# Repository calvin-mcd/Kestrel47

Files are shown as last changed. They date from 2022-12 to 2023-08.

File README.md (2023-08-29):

# Kestrel47

collaboration with Falconloft\#4615

40s keyboard inspired by the TG4x. sandwich style case with midlayers case. Supports Bluetooth enabled micro controllers with use of this [power button](https://tech.alpsalpine.com/e/products/detail/SSSS811101/) as well as smd and throughhole style diodes.

Firmware for standard atmega & rp2040 pro micro style controllers is included. Bluetooth is supported for bluemicro style controllers.

concept, case design and firmware by Falconloft\#4615, pcb design by Calvin\#0563

## Layout

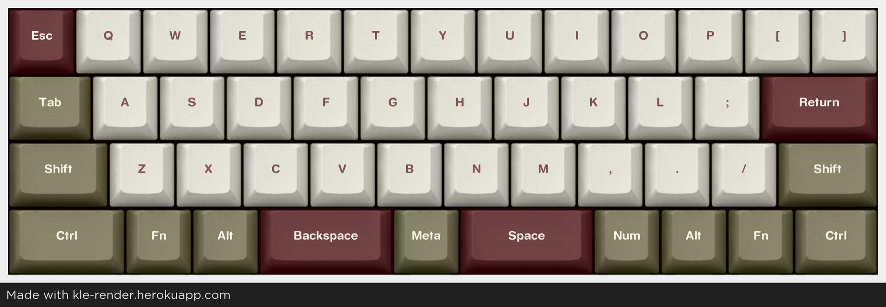
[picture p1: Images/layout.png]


[Link](http://www.keyboard-layout-editor.com/#/gists/43b69fae42faf7c21a81fad3a4cf8861)

## Pictures

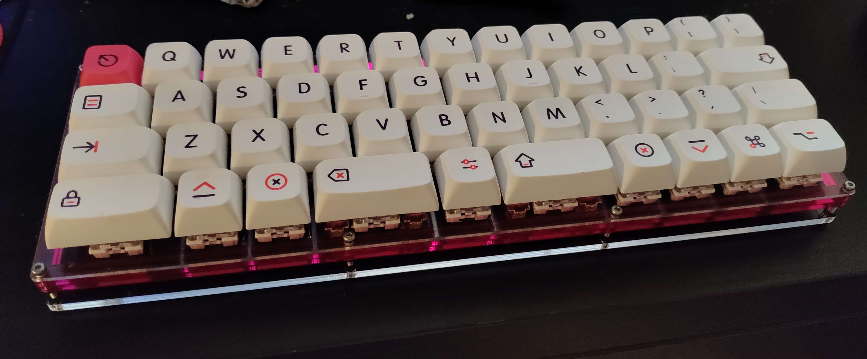
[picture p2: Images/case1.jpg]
  
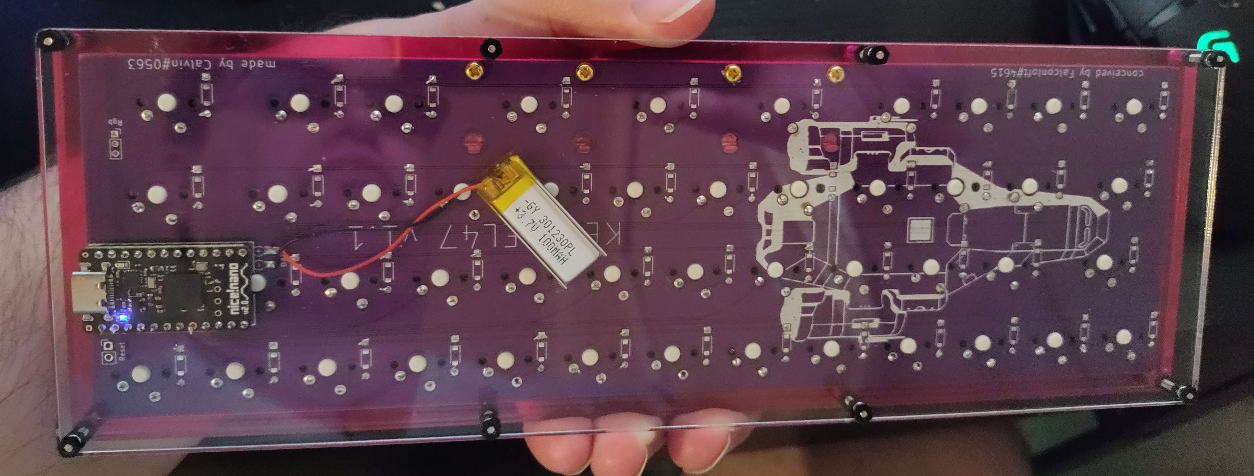
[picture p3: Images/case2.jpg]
  
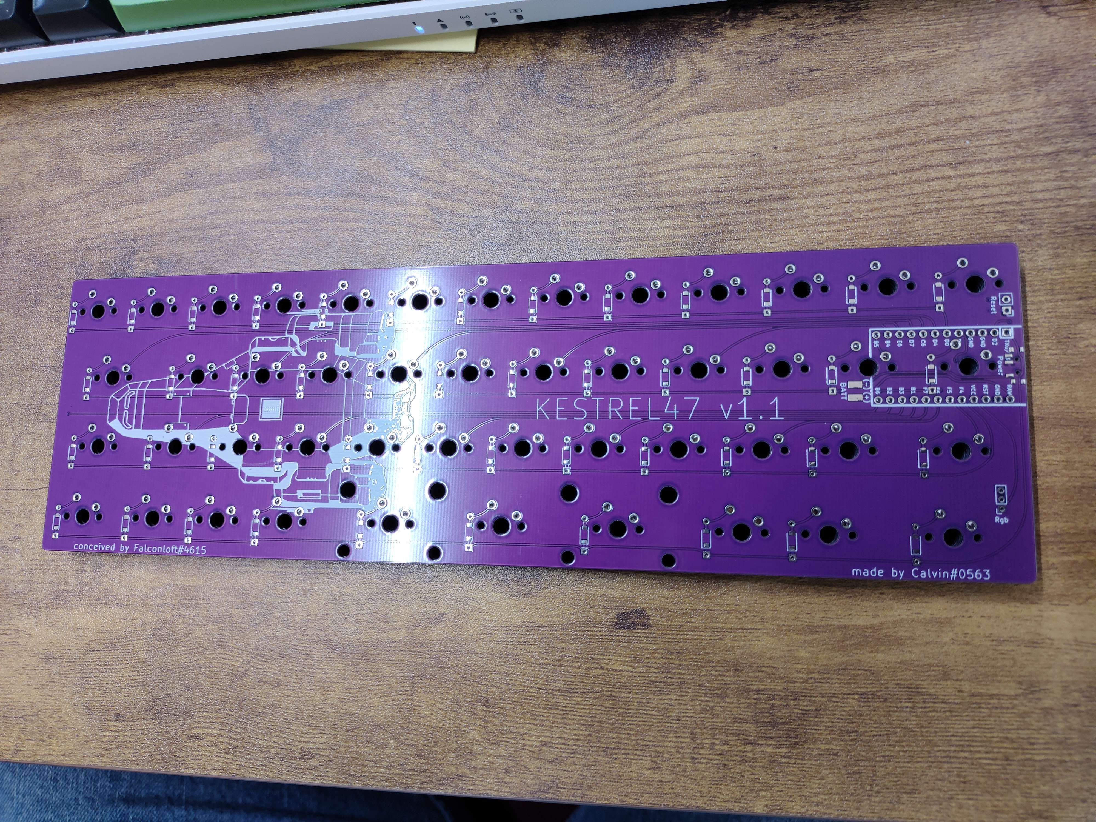
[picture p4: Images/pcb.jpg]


## Firmware

Firmware for both Atmega and rp2040 controllers is functional and included.

The Bluetooth firmware is zmk based, functional and included.

## Disclaimer

This PCB has been fully tested and confirmed to work. The members of the PCB development team are however not liable if you end up with a non-functional pcb. Order at your own risk. Support will not be provided but pull requests will be reviewed and possibly accepted.

## License

Shield: 

This work is licensed under a  
[Creative Commons Attribution-NonCommercial-ShareAlike 4.0 International License](http://creativecommons.org/licenses/by-nc-sa/4.0/).



## Credits

Any questions, contact Falconloft\#4615 & Calvin\#0563 on Discord.

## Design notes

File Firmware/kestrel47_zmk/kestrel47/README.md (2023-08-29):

# Kestrel47

Standard setup for the [Kestrel47](https://github.com/calvin-mcd/Kestrel47/) 40% keyboard.

## Board Revision and Layout Notes

This Kestrel47 implementation is for...

- rev 1.1 of the board

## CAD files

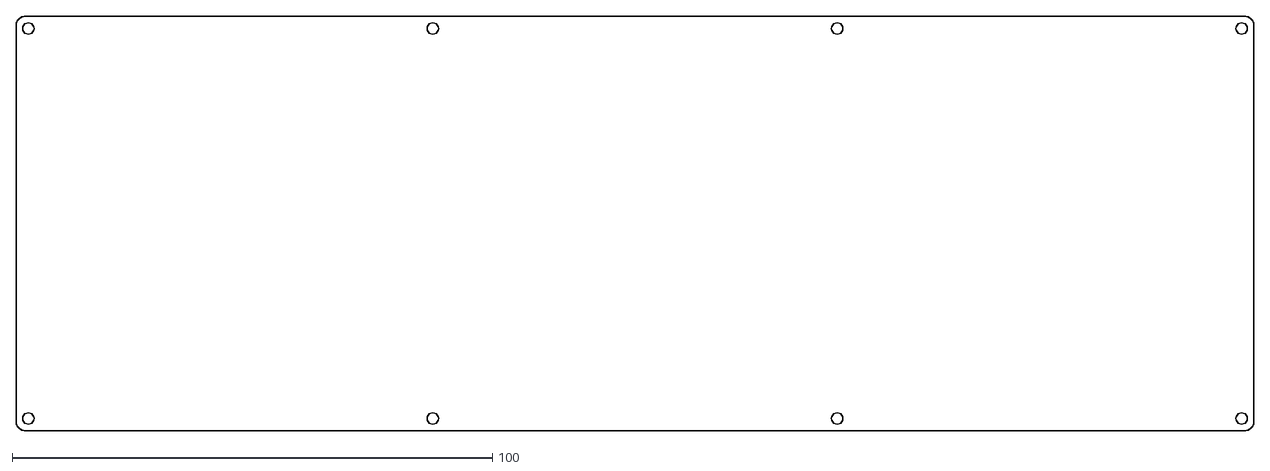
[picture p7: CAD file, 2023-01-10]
Case/kestrel47_bottom.dxf
257.8 x 86.3

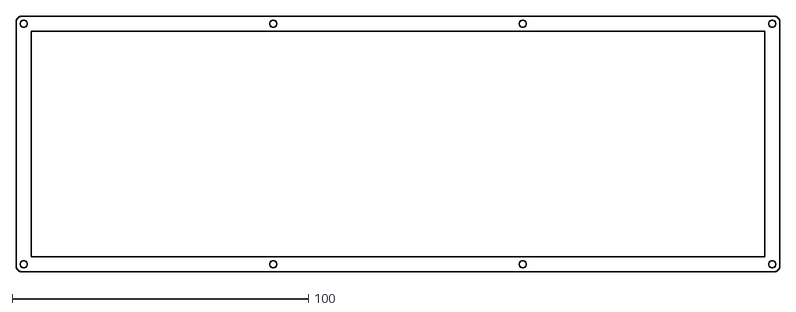
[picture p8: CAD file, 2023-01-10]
Case/kestrel47_closed.dxf
257.8 x 86.3

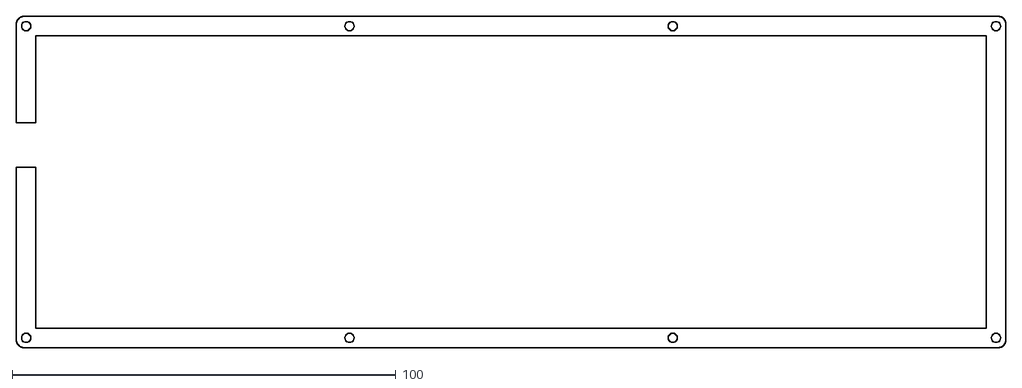
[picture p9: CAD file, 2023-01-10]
Case/kestrel47_open.dxf
257.8 x 86.3

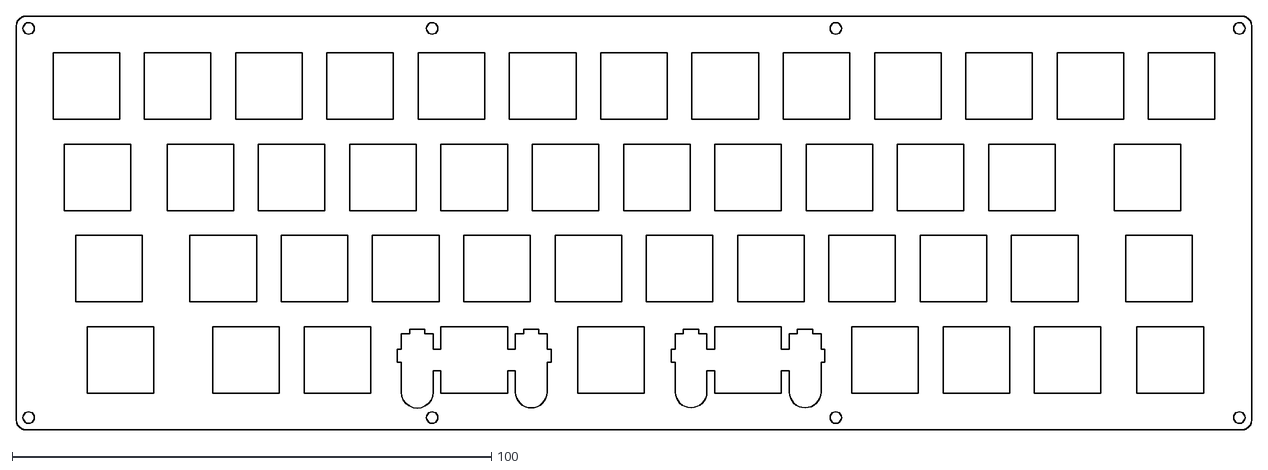
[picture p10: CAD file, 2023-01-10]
Case/kestrel47_switch.dxf
257.8 x 86.3

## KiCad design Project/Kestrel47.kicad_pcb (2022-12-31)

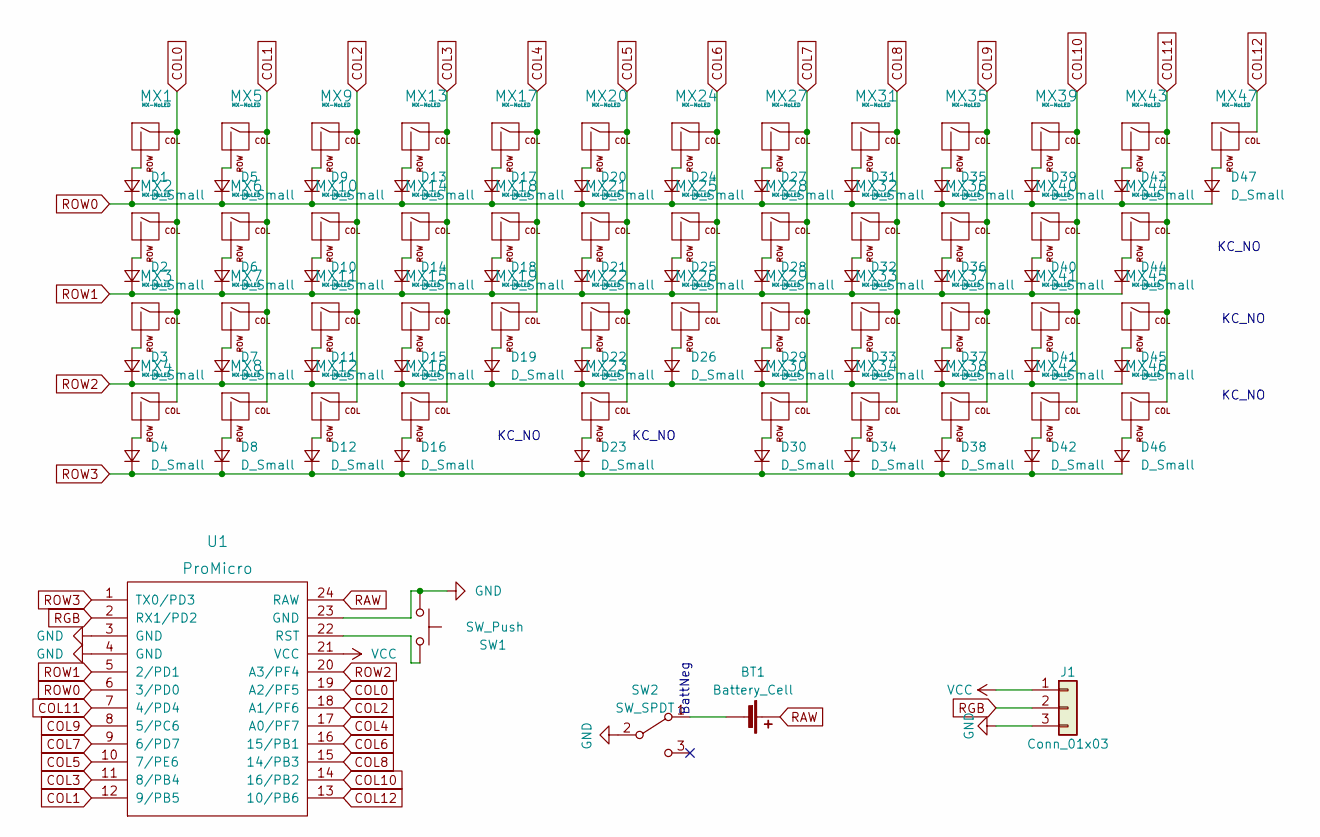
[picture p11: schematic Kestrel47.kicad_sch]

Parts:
BT1: Battery_Cell; cell_pads
D1, D2, D3, D4, D5, D6, D7, D8, D9, D10, D11, D12, D13, D14, D15, D16, D17, D18, D19, D20, D21, D22, D23, D24, D25, D26, D27, D28, D29, D30, D31, D32, D33, D34, D35, D36, D37, D38, D39, D40, D41, D42, D43, D44, D45, D46, D47: D_Small; ComboDiode
J1: Conn_01x03; PinSocket_1x03_P2.00mm_Vertical
MX1, MX5, MX6, MX7, MX8, MX9, MX10, MX11, MX12, MX13, MX14, MX15, MX17, MX18, MX19, MX20, MX21, MX22, MX23, MX24, MX25, MX26, MX27, MX28, MX29, MX31, MX32, MX33, MX34, MX35, MX36, MX37, MX38, MX39, MX40, MX41, MX42, MX43, MX47: MX-NoLED; MXOnly-1U-NoLED
MX2, MX46: MX-NoLED; MXOnly-1.25U-NoLED
MX3, MX45: MX-NoLED; MXOnly-1.5U-NoLED
MX4, MX44: MX-NoLED; MXOnly-1.75U-NoLED
MX16, MX30: MX-NoLED; MXOnly-2U-ReversedStabilizers-NoLED
SW1: SW_Push; PinHeader_1x02_P2.54mm_Vertical
SW2: SW_SPDT; switch_SSSS811101
U1: ProMicro; ArduinoProMicro

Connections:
ROW3: D4.1 (K), D8.1 (K), D12.1 (K), D16.1 (K), D23.1 (K), D30.1 (K), D34.1 (K), D38.1 (K), D42.1 (K), D46.1 (K), U1.1 (TX0/PD3)
COL0: MX1.1 (COL), MX2.1 (COL), MX3.1 (COL), MX4.1 (COL), U1.19 (A2/PF5)
COL1: MX5.1 (COL), MX6.1 (COL), MX7.1 (COL), MX8.1 (COL), U1.12 (9/PB5)
COL2: MX9.1 (COL), MX10.1 (COL), MX11.1 (COL), MX12.1 (COL), U1.18 (A1/PF6)
COL3: MX13.1 (COL), MX14.1 (COL), MX15.1 (COL), MX16.1 (COL), U1.11 (8/PB4)
COL4: MX17.1 (COL), MX18.1 (COL), MX19.1 (COL), U1.17 (A0/PF7)
COL5: MX20.1 (COL), MX21.1 (COL), MX22.1 (COL), MX23.1 (COL), U1.10 (7/PE6)
COL6: MX24.1 (COL), MX25.1 (COL), MX26.1 (COL), U1.16 (15/PB1)
COL7: MX27.1 (COL), MX28.1 (COL), MX29.1 (COL), MX30.1 (COL), U1.9 (6/PD7)
COL8: MX31.1 (COL), MX32.1 (COL), MX33.1 (COL), MX34.1 (COL), U1.15 (14/PB3)
COL9: MX35.1 (COL), MX36.1 (COL), MX37.1 (COL), MX38.1 (COL), U1.8 (5/PC6)
COL10: MX39.1 (COL), MX40.1 (COL), MX41.1 (COL), MX42.1 (COL), U1.14 (16/PB2)
COL11: MX43.1 (COL), MX44.1 (COL), MX45.1 (COL), MX46.1 (COL), U1.7 (4/PD4)
COL12: MX47.1 (COL), U1.13 (10/PB6)
GND: J1.3, SW1.1, SW2.2 (B), U1.3 (GND), U1.4 (GND), U1.23 (GND)
unnamed: BT1.2 (-), SW2.1 (A)
unnamed: D1.2 (A), MX1.2 (ROW)
unnamed: D2.2 (A), MX2.2 (ROW)
unnamed: D3.2 (A), MX3.2 (ROW)
unnamed: D4.2 (A), MX4.2 (ROW)
unnamed: D5.2 (A), MX5.2 (ROW)
unnamed: D6.2 (A), MX6.2 (ROW)
unnamed: D7.2 (A), MX7.2 (ROW)
unnamed: D8.2 (A), MX8.2 (ROW)
unnamed: D9.2 (A), MX9.2 (ROW)
unnamed: D10.2 (A), MX10.2 (ROW)
unnamed: D11.2 (A), MX11.2 (ROW)
unnamed: D12.2 (A), MX12.2 (ROW)
unnamed: D13.2 (A), MX13.2 (ROW)
unnamed: D14.2 (A), MX14.2 (ROW)
unnamed: D15.2 (A), MX15.2 (ROW)
unnamed: D16.2 (A), MX16.2 (ROW)
unnamed: D17.2 (A), MX17.2 (ROW)
unnamed: D18.2 (A), MX18.2 (ROW)
unnamed: D19.2 (A), MX19.2 (ROW)
unnamed: D20.2 (A), MX20.2 (ROW)
unnamed: D21.2 (A), MX21.2 (ROW)
unnamed: D22.2 (A), MX22.2 (ROW)
unnamed: D23.2 (A), MX23.2 (ROW)
unnamed: D24.2 (A), MX24.2 (ROW)
unnamed: D25.2 (A), MX25.2 (ROW)
unnamed: D26.2 (A), MX26.2 (ROW)
unnamed: D27.2 (A), MX27.2 (ROW)
unnamed: D28.2 (A), MX28.2 (ROW)
unnamed: D29.2 (A), MX29.2 (ROW)
unnamed: D30.2 (A), MX30.2 (ROW)
unnamed: D31.2 (A), MX31.2 (ROW)
unnamed: D32.2 (A), MX32.2 (ROW)
unnamed: D33.2 (A), MX33.2 (ROW)
unnamed: D34.2 (A), MX34.2 (ROW)
unnamed: D35.2 (A), MX35.2 (ROW)
unnamed: D36.2 (A), MX36.2 (ROW)
unnamed: D37.2 (A), MX37.2 (ROW)
unnamed: D38.2 (A), MX38.2 (ROW)
unnamed: D39.2 (A), MX39.2 (ROW)
unnamed: D40.2 (A), MX40.2 (ROW)
unnamed: D41.2 (A), MX41.2 (ROW)
unnamed: D42.2 (A), MX42.2 (ROW)
unnamed: D43.2 (A), MX43.2 (ROW)
unnamed: D44.2 (A), MX44.2 (ROW)
unnamed: D45.2 (A), MX45.2 (ROW)
unnamed: D46.2 (A), MX46.2 (ROW)
unnamed: D47.2 (A), MX47.2 (ROW)
unnamed: SW1.2, U1.22 (RST)
RAW: BT1.1 (+), U1.24 (RAW)
RGB: J1.2, U1.2 (RX1/PD2)
ROW0: D1.1 (K), D5.1 (K), D9.1 (K), D13.1 (K), D17.1 (K), D20.1 (K), D24.1 (K), D27.1 (K), D31.1 (K), D35.1 (K), D39.1 (K), D43.1 (K), D47.1 (K), U1.6 (3/PD0)
ROW1: D2.1 (K), D6.1 (K), D10.1 (K), D14.1 (K), D18.1 (K), D21.1 (K), D25.1 (K), D28.1 (K), D32.1 (K), D36.1 (K), D40.1 (K), D44.1 (K), U1.5 (2/PD1)
ROW2: D3.1 (K), D7.1 (K), D11.1 (K), D15.1 (K), D19.1 (K), D22.1 (K), D26.1 (K), D29.1 (K), D33.1 (K), D37.1 (K), D41.1 (K), D45.1 (K), U1.20 (A3/PF4)
VCC: J1.1, U1.21 (VCC)

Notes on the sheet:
KC_NO
BattNeg

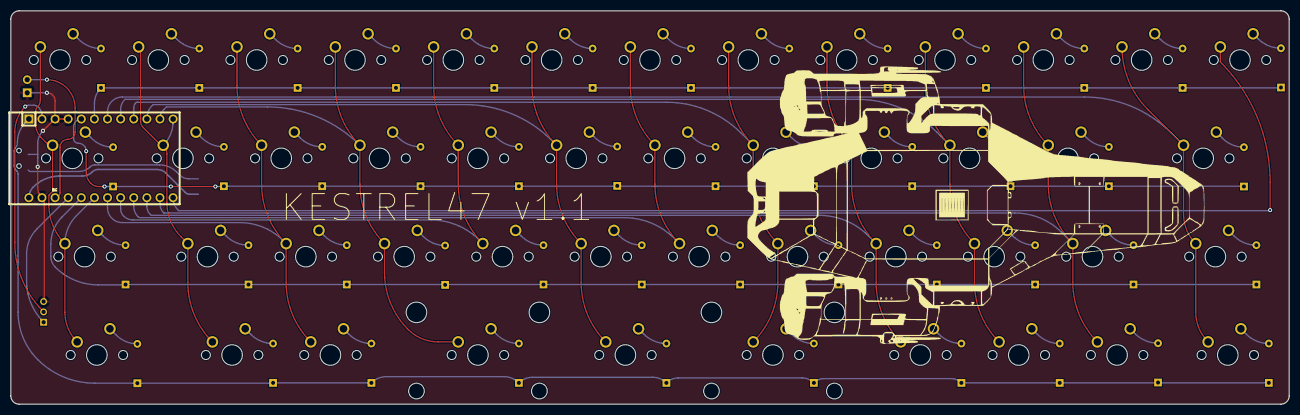
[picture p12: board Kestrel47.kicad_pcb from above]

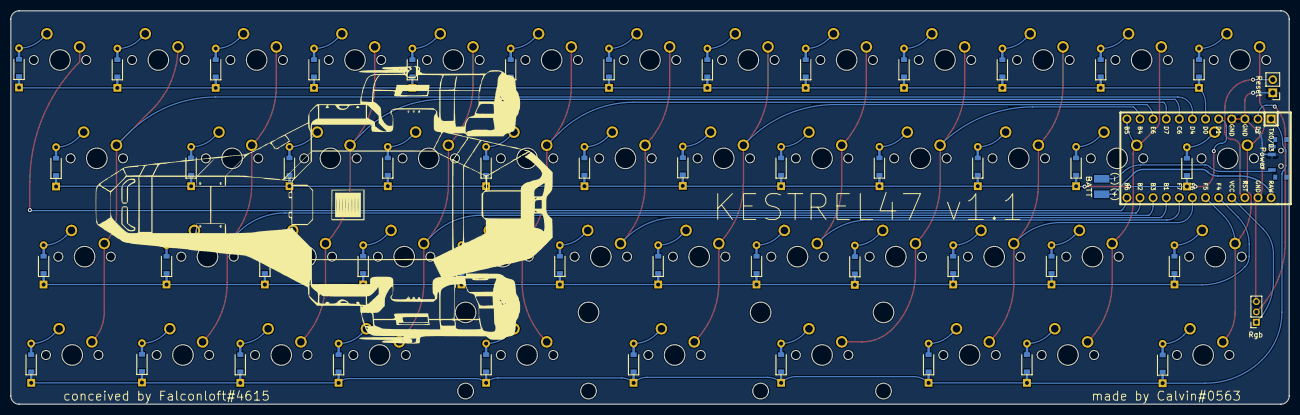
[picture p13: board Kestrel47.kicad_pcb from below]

Board: 2 copper layers, 247.6 x 76.2 mm, 99 parts (5 on the bottom side), 70 nets.

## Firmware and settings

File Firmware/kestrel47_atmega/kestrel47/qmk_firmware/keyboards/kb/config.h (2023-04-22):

#ifndef CONFIG_H
#define CONFIG_H

#include "config_common.h"

/* USB Device descriptor parameter */
#define VENDOR_ID       0xFEED
#define PRODUCT_ID      0x6060
#define DEVICE_VER      0x0001
#define MANUFACTURER    qmkbuilder
#define PRODUCT         keyboard
#define DESCRIPTION     Keyboard

/* key matrix size */
#define MATRIX_ROWS 4
#define MATRIX_COLS 13

/* key matrix pins */
#define MATRIX_ROW_PINS { D0, D1, F4, D3 }
#define MATRIX_COL_PINS { F5, B5, F6, B4, F7, E6, B1, D7, B3, C6, B2, D4, B6 }
#define UNUSED_PINS

/* COL2ROW or ROW2COL */
#define DIODE_DIRECTION COL2ROW

/* number of backlight levels */

#ifdef BACKLIGHT_PIN
#define BACKLIGHT_LEVELS 0
#endif

/* Set 0 if debouncing isn't needed */
#define DEBOUNCING_DELAY 5

/* Mechanical locking support. Use KC_LCAP, KC_LNUM or KC_LSCR instead in keymap */
#define LOCKING_SUPPORT_ENABLE

/* Locking resynchronize hack */
#define LOCKING_RESYNC_ENABLE

/* key combination for command */
#define IS_COMMAND() ( \
    keyboard_report->mods == (MOD_BIT(KC_LSHIFT) | MOD_BIT(KC_RSHIFT)) \
)

/* prevent stuck modifiers */
#define PREVENT_STUCK_MODIFIERS


#ifdef RGB_DI_PIN
#define RGBLIGHT_ANIMATIONS
#define RGBLED_NUM 0
#define RGBLIGHT_HUE_STEP 8
#define RGBLIGHT_SAT_STEP 8
#define RGBLIGHT_VAL_STEP 8
#endif

#endif

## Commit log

2022-12-16 initialised project
    [Kestrel47 switchplate.kicad_pcb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]
2022-12-17 clean up
    [Kestrel47 switchplate.kicad_pcb, Kestrel47.kicad_pcb, Kestrel47.kicad_sch]
2022-12-22 rerouting mistake, adding rgb and power button
    [Kestrel47-B_Cu.gbr, Kestrel47-B_Mask.gbr, Kestrel47-B_Paste.gbr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]
2022-12-27 cleaned up power routing
    [Kestrel47-B_Cu.gbr, Kestrel47-B_Mask.gbr, Kestrel47-B_Paste.gbr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]
2022-12-31 silkscreen update
    [Kestrel47-B_Cu.gbr, Kestrel47-B_Mask.gbr, Kestrel47-B_Paste.gbr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]
2023-01-10 work on readme, added case files
    [kestrel47_bottom.dxf, kestrel47_closed.dxf, kestrel47_open.dxf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]
2023-02-06 added diodes
    still missing blurp about switch
2023-08-29 removed old BLE firmware, added zmk based firmware
    [Kestrel47.kicad_sch]
